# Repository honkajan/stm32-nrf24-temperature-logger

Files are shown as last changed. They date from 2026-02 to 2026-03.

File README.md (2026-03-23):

# STM32 + nRF24 Temperature Logger

This repository contains an end-to-end embedded system for measuring radiator temperatures using STM32 microcontrollers and nRF24L01+ radios, with Python-based host tooling for logging and analysis.

🚧 Documentation and code will be added incrementally.

---

## System Overview

The system consists of three cooperating components:

- **Host** – Python CLI tool (`uartctl.py`) used to query measurements and log data.
- **Gateway** – STM32 + nRF24 node that bridges the UART interface to the RF network.
- **Remote Node** – STM32 + nRF24 sensor node that measures temperatures and replies to requests.

The most common transaction is the `TEMP?` command, where the host requests temperature data from the remote node through the gateway.

The following diagram illustrates the high-level request flow.

TEMP request overview

*Overview of the TEMP? transaction path between host, gateway and remote node.*

A more detailed implementation-level flow diagram is available in
[docs/diagrams/get_temperature_activity_detailed.svg](docs/diagrams/get_temperature_activity_detailed.svg).

## Repositories

The system is implemented as a set of focused repositories:

- **uartctl** – host-side Python CLI tool for interacting with the system  
  [https://github.com/honkajan/uartctl](https://github.com/honkajan/uartctl)

- **gateway-fw** – STM32 firmware for the UART-to-nRF24 gateway node  
  [https://github.com/honkajan/gateway-fw](https://github.com/honkajan/gateway-fw)

- **remote-fw** – STM32 firmware for the remote temperature measurement node  
  [https://github.com/honkajan/remote-fw](https://github.com/honkajan/remote-fw)

## Remote Measurement Node – Hardware Overview

The remote node consists of:

- STM32F103C8T6 "Blue Pill" microcontroller module
- nRF24L01+ PA/LNA 2.4 GHz RF module
- Dual NTC temperature measurement front-end
- USB-powered carrier board
- Plug-in interconnect harness (semi-permanent)

## Remote Node – Hardware Schematic (RevB)

Remote Node Schematic (RevB)

*Remote node schematic (RevB) with optimized ADC front-end filtering.*

**RevB updates:**
- Reduced ADC front-end RC filter (470 µF → 10 µF)
- Improved startup settling time (~20 s → ~3 s)

[Download schematic (PDF)](docs/hardware/exports/remote_node_schematic_revB.pdf)

> See [docs/hardware/README.md](docs/hardware/README.md) for full revision history.

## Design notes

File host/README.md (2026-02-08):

# Host Tools

This directory contains host-side tools used to interact with the embedded system
via the gateway node.

## UART CLI tool

The primary host-side interface is a Python-based UART control and logging utility,
maintained as a separate repository:

- **uartctl**: https://github.com/honkajan/uartctl

The tool provides a simple, script-friendly command-line interface for:
- discovering serial ports
- issuing request/response commands to the gateway
- fetching and logging temperature data
- producing CSV output suitable for long-running analysis and plotting

Keeping the UART tool as a standalone repository allows it to be reused across
projects while still integrating cleanly with this system.

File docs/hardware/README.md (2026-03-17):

# Remote Node Hardware

This document provides the schematic and revision history for the STM32 + nRF24 temperature sensor node.

## View schematic

PDF:
[remote_node_schematic_revB.pdf](exports/remote_node_schematic_revB.pdf)

SVG:
[remote_node_schematic_revB.svg](exports/remote_node_schematic_revB.svg)

## Source files

Editable KiCad project files:

docs/hardware/kicad/

Designed with **KiCad 9.0.7**

## Hardware revisions

### RevA
- ADC RC filter: 10 kΩ + 470 µF
- Long startup settling (~20 s required)

### RevB
- ADC RC filter: 10 kΩ + 10 µF
- Reduced startup settling (~20 s → ~3 s)
- Improved measurement responsiveness after power-up

This change significantly improves usability by reducing the delay before valid temperature readings are available after power-up.

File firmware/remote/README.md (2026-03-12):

# Remote Firmware

This directory refers to the STM32 firmware used in the remote wireless temperature measurement node.

The actual firmware source code is maintained in a separate repository:

- **remote-fw**: https://github.com/honkajan/remote-fw

The remote node:
- performs local temperature measurement
- maintains the latest sampled values
- receives RF requests from the gateway
- returns measurement payloads over the nRF24 link

For system-level architecture, protocol documentation, and diagrams, see the main repository documentation under `docs/`.

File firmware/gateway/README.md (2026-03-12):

# Gateway Firmware

This directory refers to the STM32 firmware used in the UART-to-nRF24 gateway node.

The actual firmware source code is maintained in a separate repository:

- **gateway-fw**: https://github.com/honkajan/gateway-fw

The gateway node:
- receives UART commands from the host tool
- performs RF request/response transactions with the remote node
- returns formatted UART responses back to the host

For system-level architecture, protocol documentation, and diagrams, see the main repository documentation under `docs/`.

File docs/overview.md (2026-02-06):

# System Overview

This project implements a small but complete embedded telemetry system built around STM32 microcontrollers and nRF24L01+ radios. The system measures radiator temperatures, transmits them wirelessly, and logs long-term data on a Linux host for analysis.

The focus of the project is not only on measurement accuracy, but on **system-level reliability**, **clear interfaces**, and **reproducibility**.

---

## High-level architecture

The system consists of three main components:

1. **Remote node**
2. **Gateway node**
3. **Host PC (Linux)**

Each component has a clearly defined responsibility and communicates through explicit, request/response interfaces.

---

## Remote node (STM32 + nRF24)

The remote node is responsible for:

- Measuring two radiator temperatures using NTC sensors
- Sampling temperatures periodically (≈1 Hz)
- Caching the most recent measurement
- Responding to RF requests from the gateway

The remote node does not push data autonomously. All communication is initiated by the gateway to keep RF behavior deterministic and observable.

---

## Gateway node (STM32 + nRF24 + UART)

The gateway node acts as a protocol translator:

- Wireless RF communication with the remote node
- Text-based UART communication with the host PC

Its responsibilities include:

- Issuing RF commands (ping, temperature request)
- Receiving fixed-size binary RF packets
- Converting binary payloads into human-readable UART responses
- Ensuring the UART remains silent unless a command is explicitly issued

This design allows reliable scripting on the host side without having to deal with asynchronous or unsolicited output.

---

## Host PC (Python tooling)

The host PC communicates with the gateway via a serial UART interface.

A custom Python CLI tool is used to:

- Discover serial ports
- Issue commands to the gateway
- Fetch temperature samples on demand
- Log long-running measurements to CSV files
- Perform offline analysis and visualization

The tooling is designed to be script-friendly, reproducible, and suitable for long-running data collection.

---

## Design goals

The main goals of this project are:

- Demonstrate a complete embedded system, not just isolated firmware
- Use simple, explicit protocols that are easy to debug
- Support long-running operation and validation
- Make the system understandable and reproducible by others

Further documentation covers firmware structure, communication protocols, and data analysis in more detail.

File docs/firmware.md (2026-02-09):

# Firmware Architecture

This document describes the firmware structure and design decisions for the
embedded nodes in the system. The goal is not only to explain *what* the firmware
does, but *why* it is structured the way it is.

The system consists of two STM32-based nodes with clearly separated roles:
a remote sensing node and a gateway node.

---

## Design goals

The firmware was designed with the following goals in mind:

- **Deterministic behavior**
- **Clear separation of responsibilities**
- **Minimal implicit behavior**
- **Ease of debugging and validation**
- **Support for long-running operation**

These goals influenced both the overall architecture and many smaller
implementation choices.

---

## Node roles

### Remote node

The remote node is responsible for *measurement only*.

Its main tasks are:

- Sampling two NTC temperature sensors via ADC
- Converting raw ADC values into temperatures
- Maintaining a cached copy of the most recent sample
- Responding to RF requests from the gateway

The remote node does **not** initiate communication and does not transmit
periodically. This avoids unnecessary RF traffic and makes system behavior
fully observable from the gateway.

#### Sampling and caching

Temperature sampling is performed periodically (≈1 Hz).  
Each sample updates an internal cache containing:

- temperatures in millidegrees Celsius
- raw ADC readings
- status flags
- timestamp or age information

When a temperature request is received over RF, the cached sample is returned
immediately without blocking on a new ADC conversion.

This decoupling ensures predictable RF response times.

---

### Gateway node

The gateway node acts as an explicit boundary between:

- wireless RF communication, and
- host-side UART communication

Its responsibilities include:

- Issuing RF commands to the remote node
- Receiving and validating RF responses
- Translating binary RF payloads into textual UART responses
- Enforcing request/response-only UART behavior

The gateway does not perform temperature sampling itself.

---

## Pull-based communication model

Both RF and UART communication follow a strictly pull-based model:

- No background transmissions
- No unsolicited output
- All data transfers are initiated by explicit requests

This model was chosen to:

- simplify host-side tooling
- avoid synchronization issues on UART
- make failures and timeouts explicit
- support reliable scripting and automation

---

## Fixed-size RF packets

RF communication uses fixed-size (32-byte) packets.

Benefits of this approach:

- predictable memory usage
- simple serialization and deserialization
- reduced risk of buffer overflows
- easier debugging and inspection

The RF payload layout is documented separately in `docs/protocol.md`.

---

## Error handling and robustness

The firmware favors explicit error reporting over silent retries.

Examples:

- RF timeouts result in a failed transaction
- Invalid or missing responses are propagated to the host
- No automatic retry loops at the firmware level

Retry and recovery strategies are implemented at the host side, where timing
and policy decisions are easier to adjust.

---

## Debugging and validation

Several design choices were made specifically to support debugging:

- Human-readable UART protocol
- No asynchronous UART output
- Clear command/response boundaries
- Exposure of raw ADC values alongside converted temperatures

These choices allow validation of the entire signal chain:

NTC sensor → ADC → firmware → RF → gateway → UART → Python tooling

---

## Real-world operation

The firmware has been validated in long-running operation:

- continuous sampling over many hours
- observed RF packet loss below 1%
- temperature behavior matching physical heating system dynamics

This validation influenced confidence in the chosen architecture and protocols.

---

## Summary

The firmware is intentionally simple, explicit, and conservative in its behavior.
Rather than optimizing for throughput or minimal latency, it prioritizes
predictability, observability, and correctness in a real-world environment.

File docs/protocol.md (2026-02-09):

# Communication Protocols

This document describes the communication protocols used in the system, covering
both the wireless RF protocol between embedded nodes and the UART protocol between
the gateway and the host PC.

The protocols are intentionally simple, explicit, and deterministic to support
reliability, debuggability, and reproducibility.

---

## Design principles

The following principles guided the protocol design:

- **Request/response only**
  No unsolicited messages are sent on RF or UART.

- **Deterministic behavior**
  All communication is initiated explicitly by the requester.

- **Human-readable where possible**
  UART uses line-based ASCII text for ease of debugging and scripting.

- **Fixed-size binary where appropriate**
  RF packets use fixed-size binary payloads for efficiency and predictability.

- **Clear separation of responsibilities**
  Each layer (remote, gateway, host) performs a single well-defined role.

---

## RF protocol (gateway ↔ remote)

### Overview

The RF protocol is used between the gateway node and the remote temperature-sensing node.
Communication is always initiated by the gateway.

Key characteristics:
- Fixed-size packets (32 bytes)
- Little-endian encoding
- Simple command/response semantics
- No periodic or autonomous transmissions from the remote node

---

### RF commands

| Command | Direction | Description |
|---|---|---|
| `PING` | Gateway → Remote | Connectivity check |
| `PONG` | Remote → Gateway | Response to `PING` |
| `GTMP` | Gateway → Remote | Request latest temperature sample |
| `TMP!` | Remote → Gateway | Temperature data response |

---

### Temperature response payload (`TMP!`)

The temperature response payload has the following layout
(all values little-endian):

| Field | Type | Description |
|-----|---|---|
| `T0_mC` | `int32` | Radiator 1 temperature in millidegrees Celsius |
| `T1_mC` | `int32` | Radiator 2 temperature in millidegrees Celsius |
| `flags` | `uint16` | Status and validity flags |
| `age_ms` | `uint16` | Age of the sample in milliseconds |
| `ADC0` | `uint16` | Raw ADC reading for sensor 1 |
| `ADC1` | `uint16` | Raw ADC reading for sensor 2 |

The remote node maintains a cached temperature sample updated periodically
(≈1 Hz). When a `GTMP` request is received, the most recent cached sample
is returned immediately.

---

## UART protocol (gateway ↔ host)

### Overview

The UART protocol connects the gateway node to a host PC.
It is a line-oriented, ASCII-based protocol designed for interactive use
and for scripting from host-side tools.

Key characteristics:
- One command per line
- Newline-terminated (`\n`)
- One-line response per command
- No unsolicited output from the gateway

This design allows robust use from scripts without needing to handle
asynchronous or background messages.

---

### UART commands

| Command | Description | Response |
|---|---|---|
| `PING` | Gateway connectivity check | `PONG` |
| `ID?` | Query firmware identification | Free-form string |
| `VER?` | Query firmware version | `MAJOR.MINOR.PATCH` |
| `UPTIME?` | Query uptime | Decimal milliseconds |
| `RPING?` | RF ping remote node | `RPONG` or error |
| `TEMP?` | Fetch remote temperature | `TEMP ...` |

---

### Temperature response (`TEMP?`)

The temperature response is a single line of key=value fields:

```
TEMP ADC0=2070 ADC1=2015 T0=24966 T1=25926 age=856 flags=0x0007
```

Fields:
- `ADC0`, `ADC1` – raw ADC values
- `T0`, `T1` – temperatures in millidegrees Celsius
- `age` – sample age in milliseconds
- `flags` – status bitmask

This format is intentionally easy to parse from both shell scripts and
higher-level tools.

---

## Error handling

- Timeouts result in no response
- Failed RF operations are reported by the gateway
- Host-side tools are expected to treat missing or malformed responses
  as failed samples

No retries are performed automatically at the protocol level; retry logic
is handled by the host tooling when appropriate.

---

## Rationale for no unsolicited output

The gateway never prints data unless a command is received.

This ensures:
- predictable behavior for scripting
- clean separation between control and logging
- compatibility with long-running host-side data collection

This constraint was chosen deliberately to avoid subtle failures in
serial-based automation.

---

## Summary

The protocols favor simplicity and explicitness over throughput or complexity.
They are designed to be easy to inspect, debug, and extend while supporting
long-running, real-world measurements.

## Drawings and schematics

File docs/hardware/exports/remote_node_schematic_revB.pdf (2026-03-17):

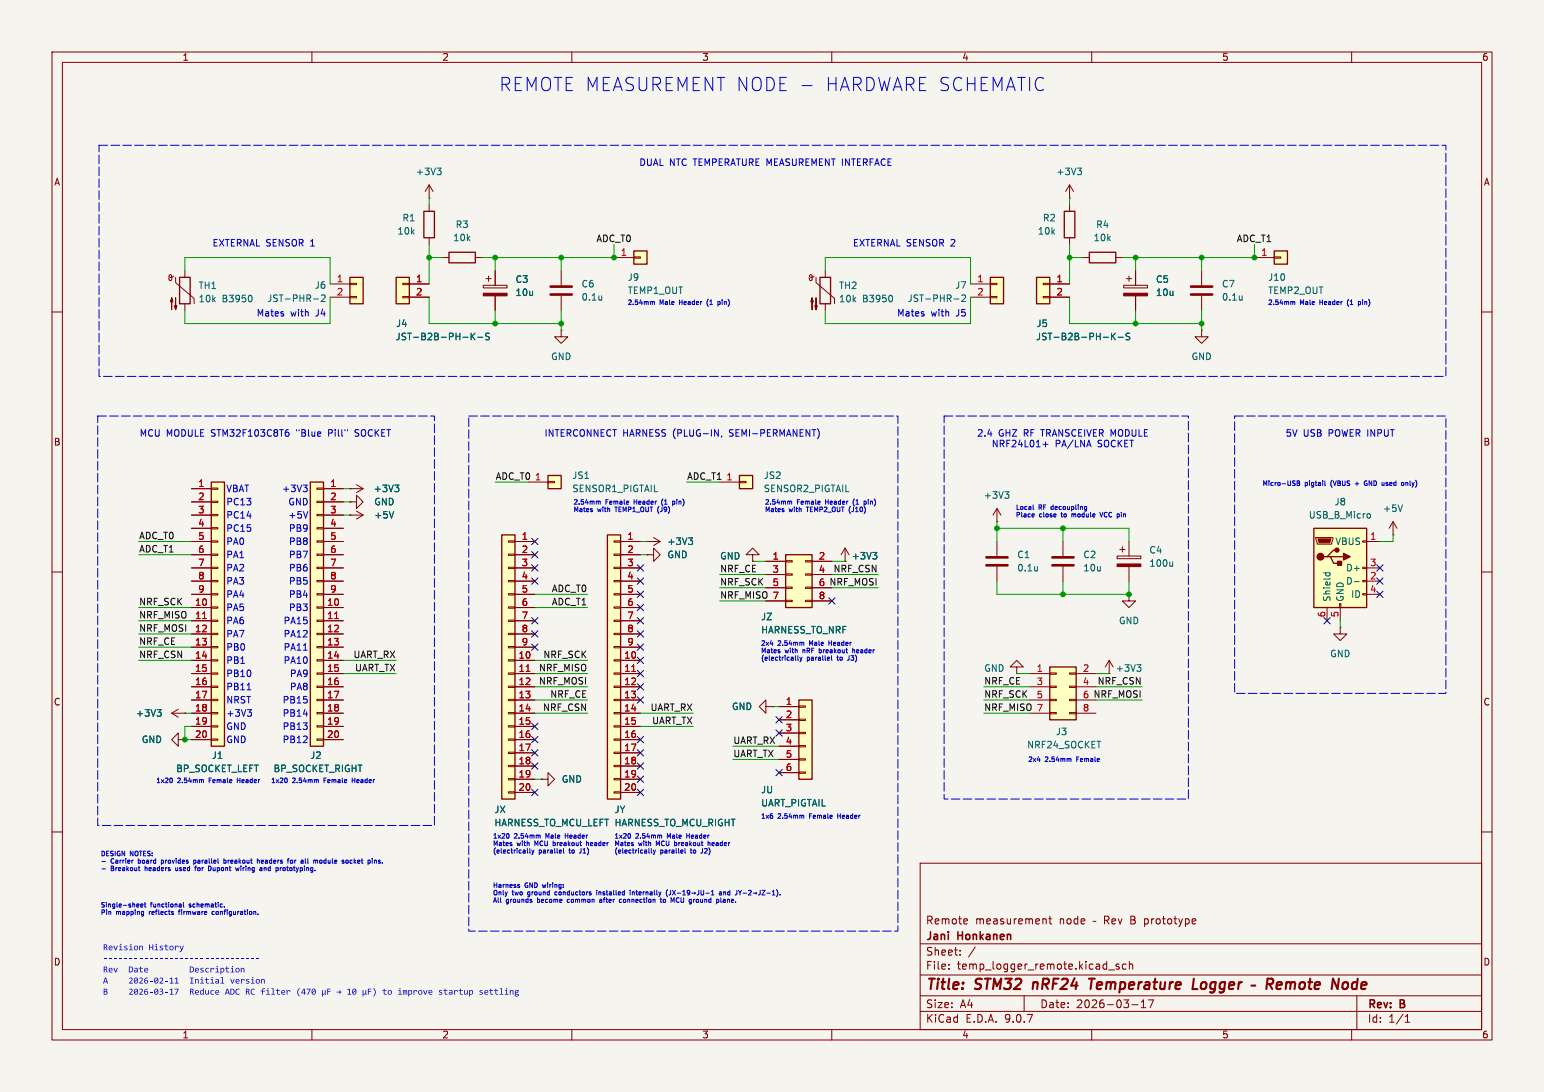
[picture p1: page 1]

EXTERNAL SENSOR 2 Mates with J5

Id: 1/1 Title: STM32 nRF24 Temperature Logger þÿ Remote Node

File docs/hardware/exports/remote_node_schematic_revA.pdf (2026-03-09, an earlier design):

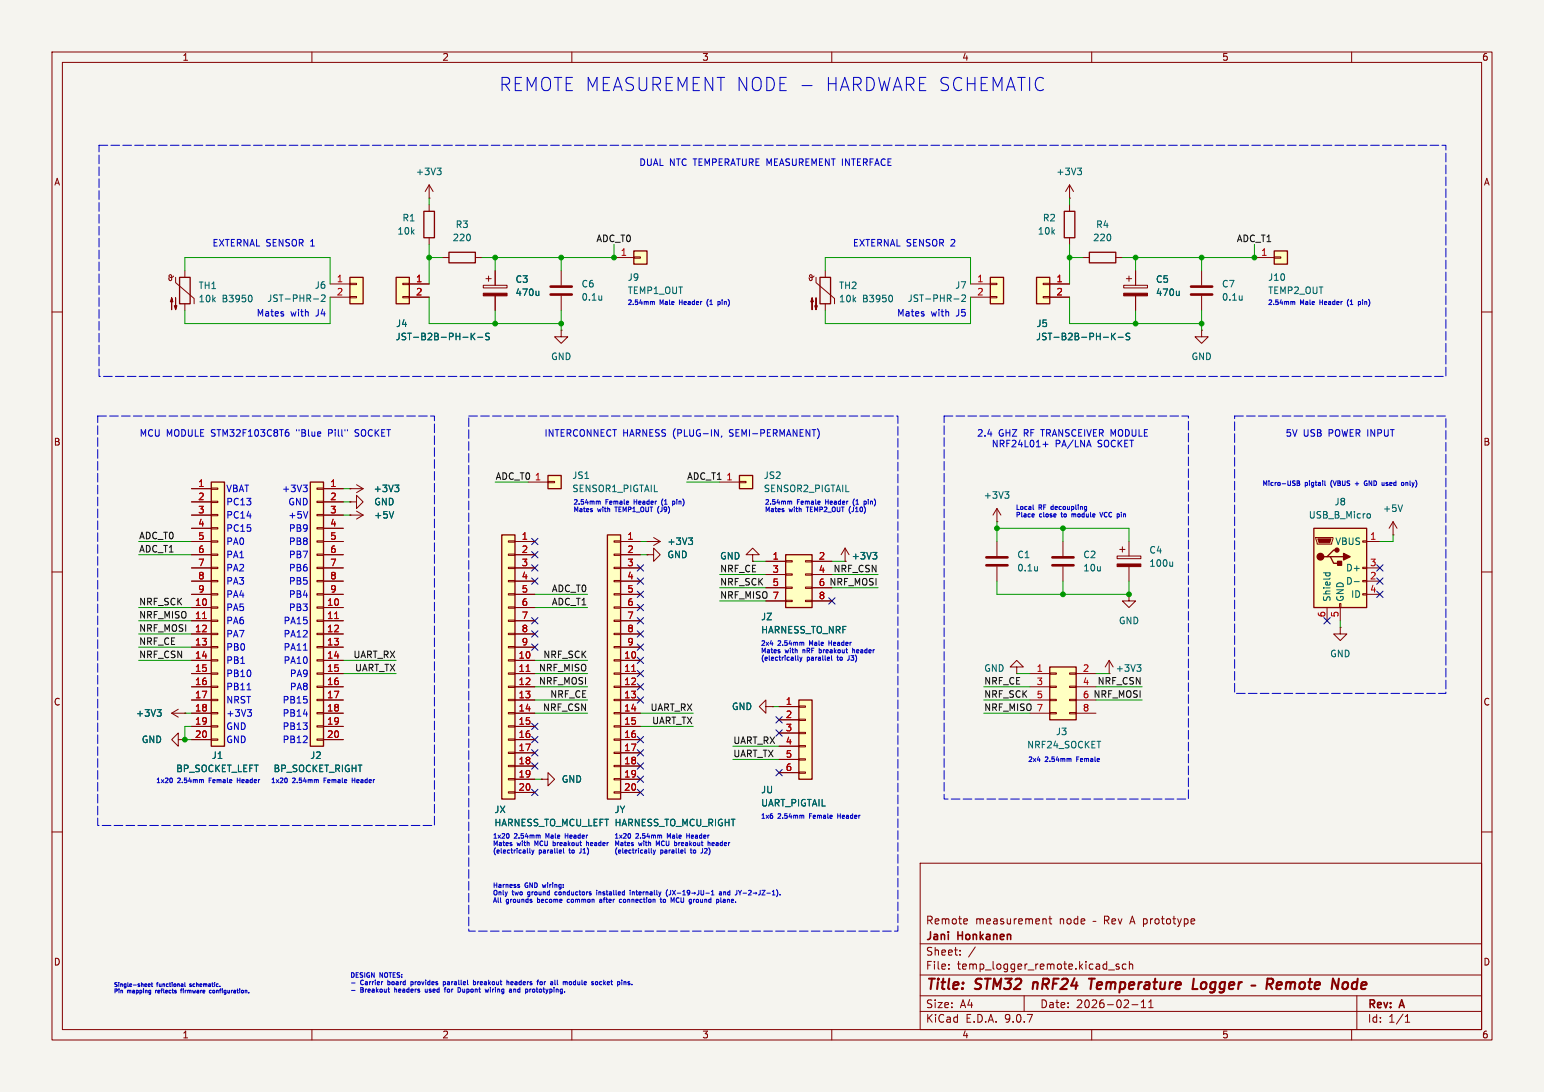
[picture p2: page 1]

Id: 1/1 Title: STM32 nRF24 Temperature Logger þÿ Remote Node

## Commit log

2026-02-08 Link to uartctl host-side CLI tool repository
2026-02-09 Document RF and UART communication protocols
2026-02-21 docs: add remote node schematic (SVG/PDF) and embed in README
2026-03-07 Add TEMP? system overview and activity diagrams
    Embed overview diagram in README and add detailed flow diagrams under docs/
2026-03-07 Improve README: add caption and link to detailed TEMP? flow diagram
2026-03-09 Reorganize documentation layout to separate diagrams and hardware assets.
    Changes:
    - move PlantUML diagrams to docs/diagrams/
    - move schematic exports to docs/hardware/exports/
    - add KiCad schematic sources in docs/hardware/kicad/
    - update README paths to match new structure
    - regenerate schematic SVG/PDF exports with background enabled
    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
    [temp_logger_remote.kicad_sch]
2026-03-17 Update README: switch to RevB schematic and document ADC filter improvement
    [temp_logger_remote.kicad_sch]
2026-03-23 docs: add links to component repositories (uartctl, gateway-fw, remote-fw)
